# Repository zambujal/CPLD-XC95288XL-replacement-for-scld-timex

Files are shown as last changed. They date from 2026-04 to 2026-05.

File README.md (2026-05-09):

# Timex SCLD CPLD Replacement (TC2068)
Target device: Xilinx XC95288XL CPLD

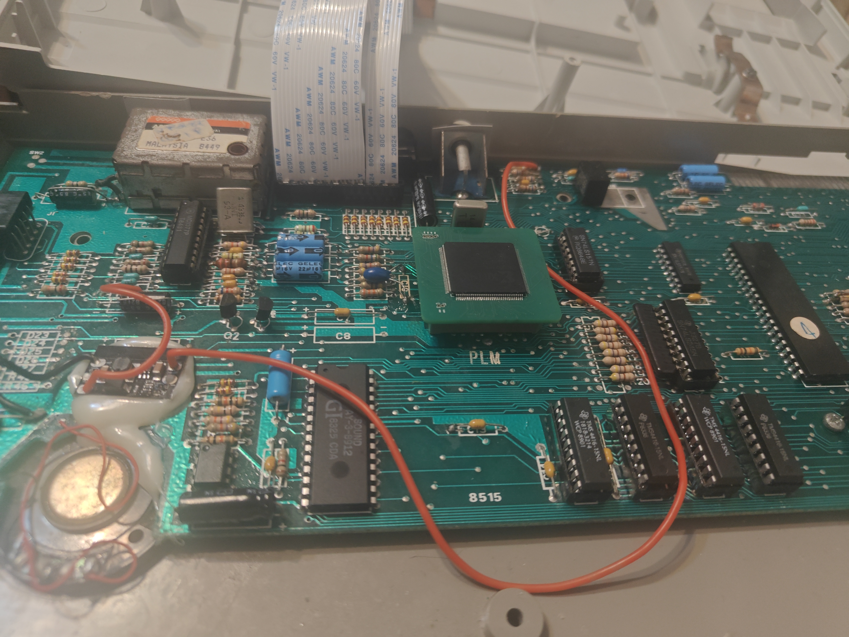
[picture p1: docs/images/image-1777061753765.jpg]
Working Setup


A fully working CPLD replacement for the Timex SCLD — validated on real hardware.

✔ Timing fixes
✔ CMOS Z84 compatible
✔ NMOS Z80 compatible
✔ Tested on real hardware

> This is not just a simulation model — this version works on real hardware.
---
### ERRATA: 
# ERRATA - scld_devboard.vhd

## Output Pin High Impedance - Code Bug

### Problem

The `OE` signal is hardwired to `'1'`, which means the condition:

```vhdl
SIGNAL <= SIGNAL_o_s WHEN OE='1' else 'Z';
```

**never** produces high impedance on any output pin. This is a **code bug**, not a Xilinx hardware limitation.

The XC95288XL correctly implements tristate output buffers (OBUFT) when the condition actually varies — as demonstrated by the `CPUCLK` fix, where using `CPUCLK_o_s='0'` as the condition produces true tristate behaviour.

### Consequence

All output pins remain **push-pull at 3.3V**. Pull-up resistors placed on these output pins have no effect on the HIGH level, since the CPLD actively drives 3.3V. The output will never float to allow an external pull-up to reach 5V.

Pull-ups are only effective where true tristate occurs or on input/bidirectional pins.

### Signal Status

| Signal | Status | Notes |
|---|---|---|
| `CPUCLK` | ✅ Fixed | Condition changed to `CPUCLK_o_s='0'` — true tristate. Use 1kΩ pull-up to 5V (max IOL = 8mA per datasheet). Required for CMOS Z80 compatibility. |
| `TPOUT` | ✅ Fixed | External audio buffer added. |
| `INT` | ✅ Fixed | Open-drain via `'0'/'1'` — correct behaviour, no pull-up to `'Z'` needed. |
| `D`, `MA` | ✅ OK | Bidirectional `inout` — tristate works correctly. |
| `KB` | ✅ OK | Input only — 10kΩ pull-ups correct and required. |
| All other outputs | ⚠️ Push-pull 3.3V | Functional for 5V TTL/CMOS receivers (VIH min = 2.0V). No external buffer needed unless 5V level is required. |

### What Works Despite the Bug

The 3.3V push-pull output is sufficient for most 5V TTL and CMOS receivers (VIH min = 2.0V). The system works correctly with an NMOS Z80. For CMOS Z80, the CPUCLK requires a higher voltage level — fixed with the true tristate + pull-up solution above.

### TODO

- `CPUCLKB` — may benefit from external buffer if CMOS Z80 is used.
- Review and fix the `OE` condition across all output assignments, replacing with signal-specific conditions where true tristate is required.

### Kicad final Beta PCB

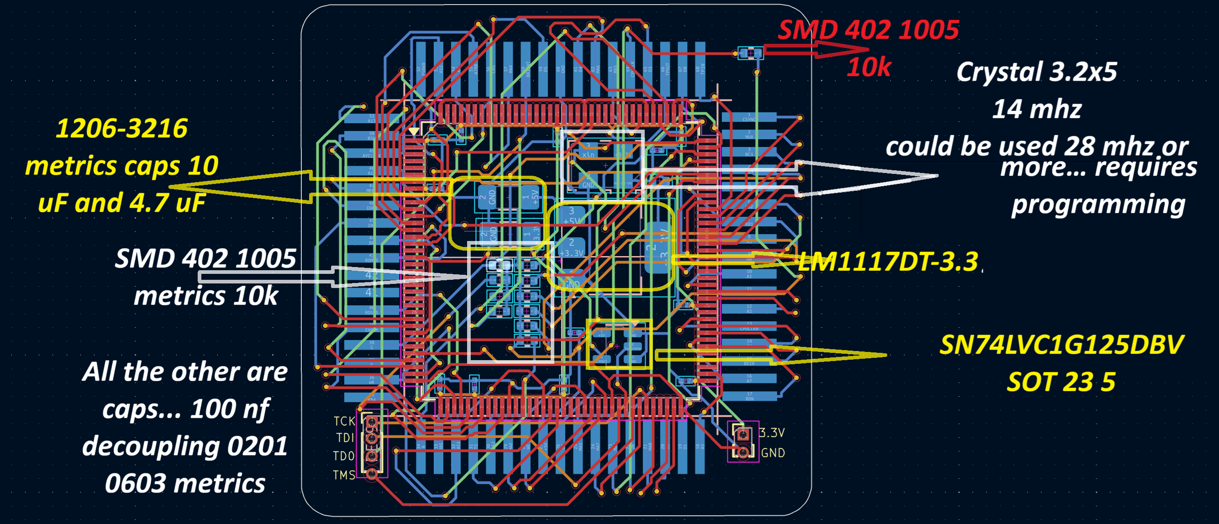
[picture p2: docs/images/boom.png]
kicad work


My last iteration of the PCB (work in progress...maybe). You might use 10uF on both rails 5v and 3.2v ... I really don't know why I changed from two caps at same value 10 uF, 10 uF is great for the two big caps... don't used electrolitic though "space"... I had to use smaller stuff, but in the end I guess ...I could had used bigger stuff to be easier to solder.

---

## 🎥 Demo (Real Hardware)

> ✔ Proof of real hardware operation — not just simulation

### CPLD Replacement Running (Timex 2048 "Timmy")

https://www.youtube.com/watch?v=t5ia4-bkabo

---

### CPLD Replacement Running (Timex 2068)

https://www.youtube.com/watch?v=evhCbX4_XCQ

---

## 📸 Hardware & Debug

> Real hardware validation using logic analysis and live system testing.

### Logic Analyzer (Timing Validation)

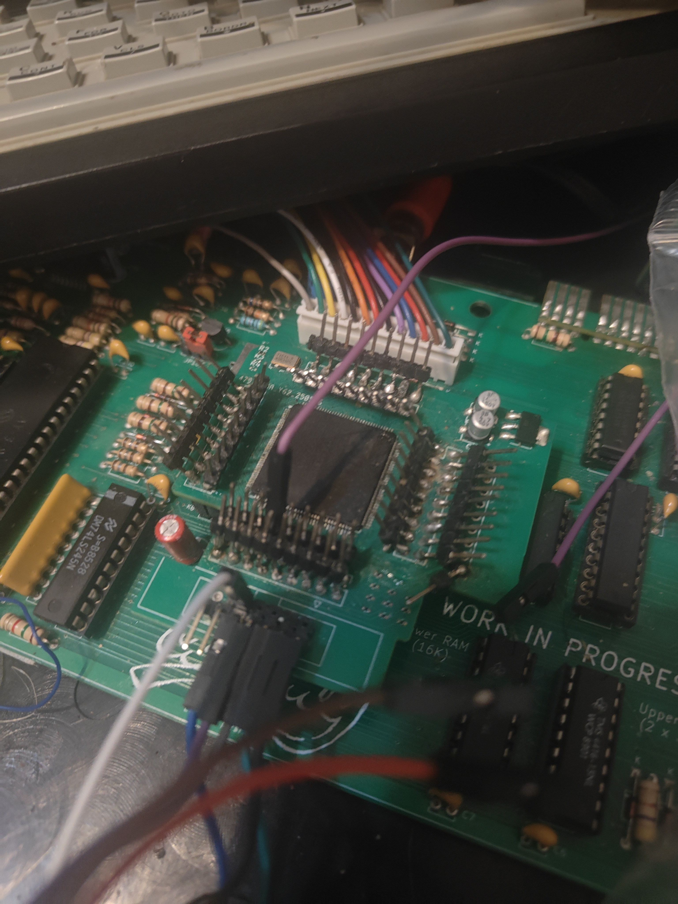
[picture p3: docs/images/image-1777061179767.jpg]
Logic Analyzer


Captured signals used to debug and align timing (MREQ, RAS, CAS, multiplexing).

---

### Timex 2048 ("Timmy") Running with Guzman Logic Analyzer

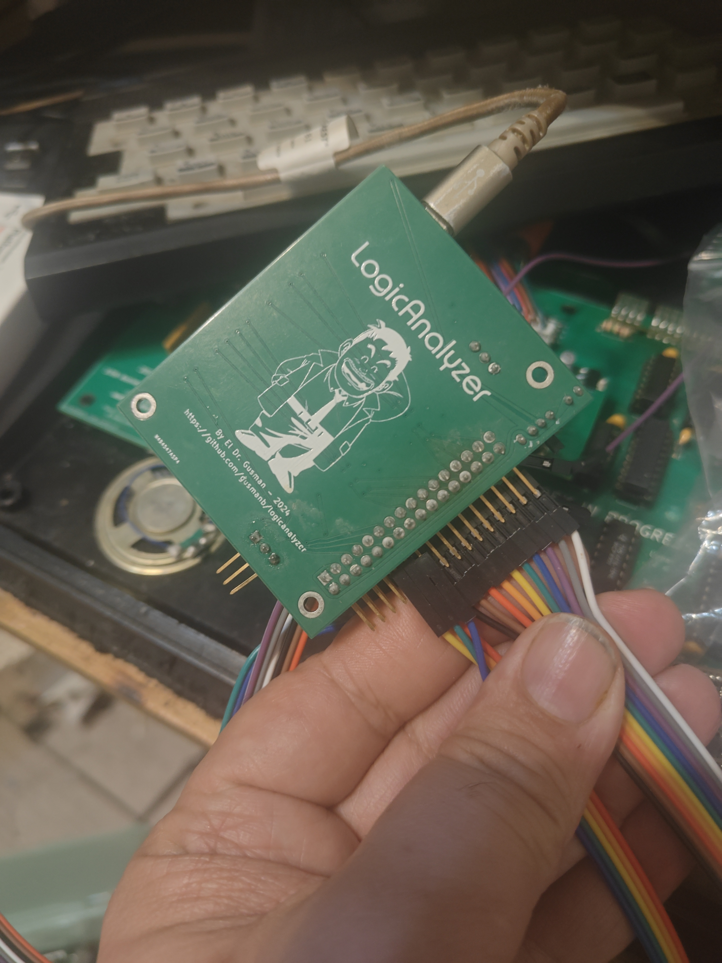
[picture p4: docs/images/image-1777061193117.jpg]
Timmy Running


System running with CPLD-based SCLD replacement, monitored using a Guzman logic analyzer.

---

### Timex 2048 Test System ("Timmy")

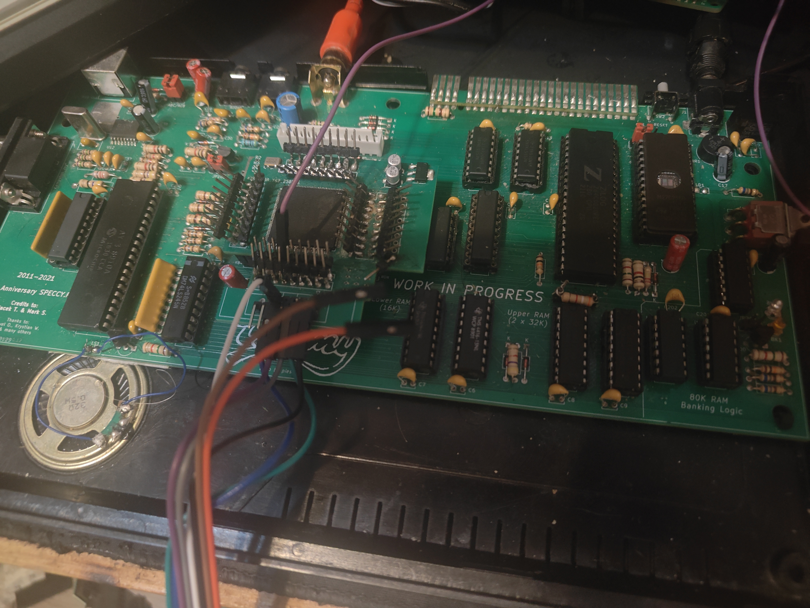
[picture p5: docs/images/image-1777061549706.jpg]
Timmy Board


Initial test platform where the CPLD implementation was first validated.

---

## 🔌 Hardware Integration Details

The CPLD board was designed to interface with the original Timex hardware using a practical and non-invasive approach.

> ⚠️ No permanent modification to the original system is required (after socket installation).

---

### CPLD Prototype (Hand-Assembled)

CPLD Prototype

Hand-assembled CPLD final prototype (beta version) .

CPLD Prototype

---

### Development Setup (Debug & Measurement)

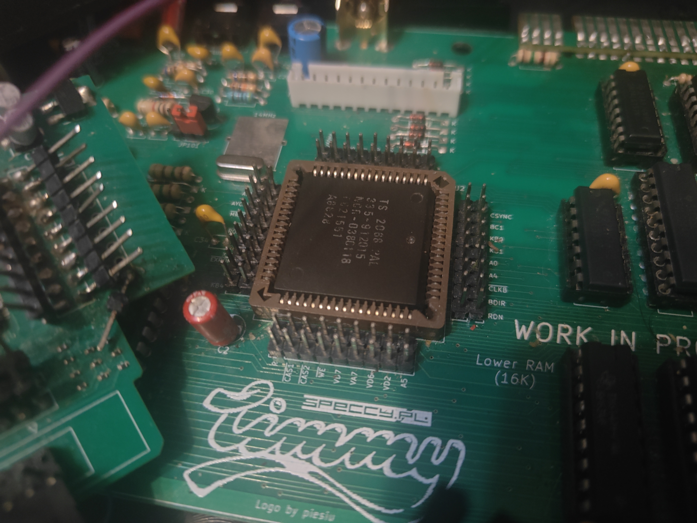
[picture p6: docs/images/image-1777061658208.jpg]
Prototype Debug


Temporary wiring and probe points were used during development to access internal signals for measurement and debugging.

These connections were used to:

* Probe critical signals (MREQ, RAS, CAS, etc.)
* Validate timing behaviour
* Debug hardware interactions

⚠️ Note:
Signal artifacts such as spikes/noise observed during this stage were related to the measurement setup, not the final design.

---

### Final Hardware Integration

Final Integration

Final CPLD implementation using right-angle (90°) pin headers.

---

### 90° Pin Integration Technique (Final Design)

Right-angle (90°) pin headers are used as part of the final design to interface the CPLD board with the installed PLCC socket.

This provides:

* Correct alignment with the socket
* Reliable electrical connections
* Mechanical stability
* Easy installation and removal

---

### PLCC Socket Adaptation

The original SCLD is soldered directly to the motherboard in Timex machines.

For this project, a PLCC socket was installed to allow easy testing and replacement without repeatedly soldering components.

This enables:

* Safe insertion and removal of the CPLD board
* Faster development iterations
* Reduced risk of damage to the motherboard

---

## ⚡ Quick Start

1. Program the CPLD with `scld_devboard.jed`
2. Insert into the installed PLCC socket
3. Power on

Done.

---

## 🧠 Overview

This project implements the Timex TC2068 SCLD using a CPLD.

Used in:

* Timex Computer 2048
* Timex Computer 2068

The SCLD is responsible for:

* Memory paging
* Video timing
* Bus arbitration
* DRAM access

---

## 🔧 What was fixed / improved

The original implementation worked on the Timex 2048 with some limitations and was implemented on a smaller CPLD.

However, it was incomplete and did not correctly support key features required for full Timex 2068 compatibility.

This implementation focuses on correct behaviour on real hardware and full system compatibility.

Key improvements include:

- Proper support for Timex 2068 memory paging  
- Implementation of missing I/O behaviour (`IN FF`, `IN F4`)  
- Correct handling of bank switching and EXROM behaviour  
- Timing fixes for reliable operation with both NMOS and CMOS Z80 CPUs  
- Improved stability and DRAM access behaviour  
- Full validation on real hardware (not just simulation)  
---

## 🧪 Development Process

* Started from original VHDL implementation
* Observed incorrect behaviour on real hardware
* Analysed signals using a logic analyzer
* Adjusted timing and internal logic
* Tested with multiple Z80 variants (NMOS / CMOS)
* Validated behaviour against real systems

---

## 🧪 Development Approach

The project evolved through direct hardware testing rather than strict schematic-first design.

Key fixes were implemented and validated directly on the PCB.

---

## 🧰 Hardware

### Final PCB

`Hardware/PCB/Beta/`

Final PCB design used for the working CPLD-based SCLD replacement.

---

### Prototype PCB

`Hardware/PCB/prototype`

Early prototype used during development and testing.

---

### Prototype Schematic

`Hardware/Schematics`

⚠️ Note:
This schematic corresponds to the prototype stage and may differ from the final PCB.

---

## 💾 Firmware

### Prebuilt

`firmware/jed`

* `scld_devboard.jed` → ready to program

---

### Source Code

`firmware/src/`

* VHDL implementation of the SCLD

---

### Constraints

`firmware/constraints/`

* UCF file defining CPLD pin mapping

---

### Xilinx Project

`firmware/xilinx/full_project/`

Full Xilinx ISE project used during development.

⚠️ Note:
Includes generated files (`remote/`, logs, etc.) to preserve the working environment.

Rebuilding is optional — the `.jed` file is sufficient.

---

## 🔍 Validation

Validated against real hardware:

* Video output behaviour
* Memory timing
* System stability
* CPU interaction timing

---

## 🙏 Credits

Based on work from:

- Load ZX Spectrum Museum  
- Álvaro Lopes  
- Paulo Cortesão  

Support:
- João Diogo 
- Hugo Pinto
- Marco Pais
- Inácio Santos
- Fernando

---

### 🧪 Technical Support & Testing

Special thanks to Rui Ribeiro:

- Provided  ROMs used for validation  
- Helped verify behaviour against real systems  
- Shared knowledge of Timex hardware and timing and the weird timex 2068 paging...

---

### 🧠 Implementation (VHDL, Hardware & PCB Design)

- António Vítor  

Complete implementation and validation:

- VHDL development and debugging  
- Timing fixes (MREQ, RAS/CAS, multiplexing)  
- Hardware design and integration  
- PCB design using KiCad  
- CPLD implementation and testing  
- Real hardware validation  

This includes both the logic implementation and the full hardware solution.

---

## 📜 License

Creative Commons Attribution-ShareAlike 4.0 International License

https://creativecommons.org/licenses/by-sa/4.0/

---

## ⚖️ Trademarks

TIMEX is a trademark of TIMEX GROUP USA, INC

The authors are not affiliated with or endorsed by the trademark holders.

Xilinx is a registered trademark of Xilinx, Inc.

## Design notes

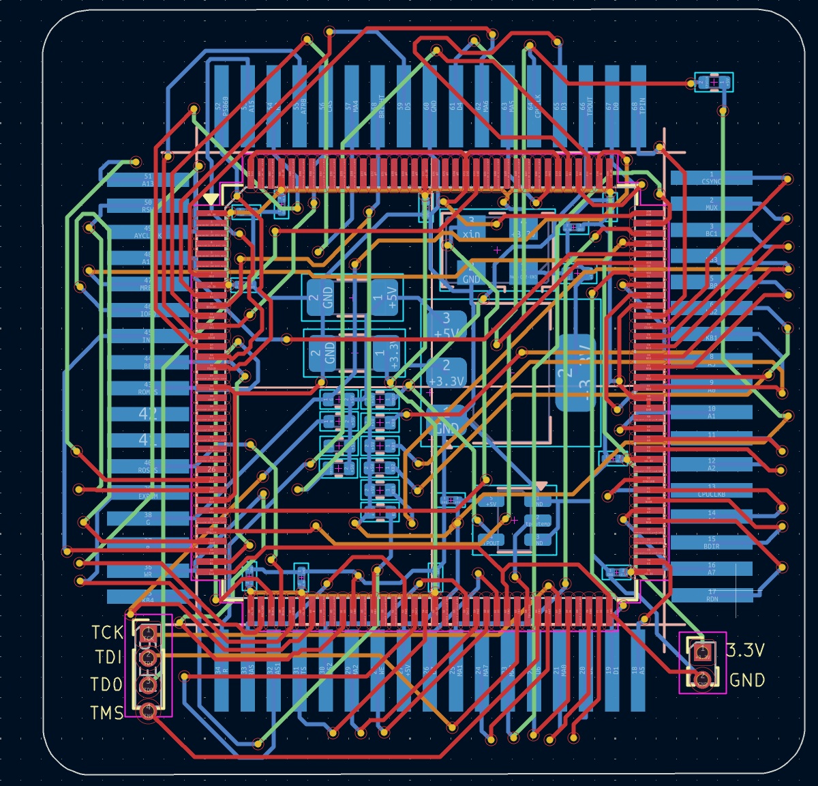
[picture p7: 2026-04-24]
docs/images/kicad1.jpg

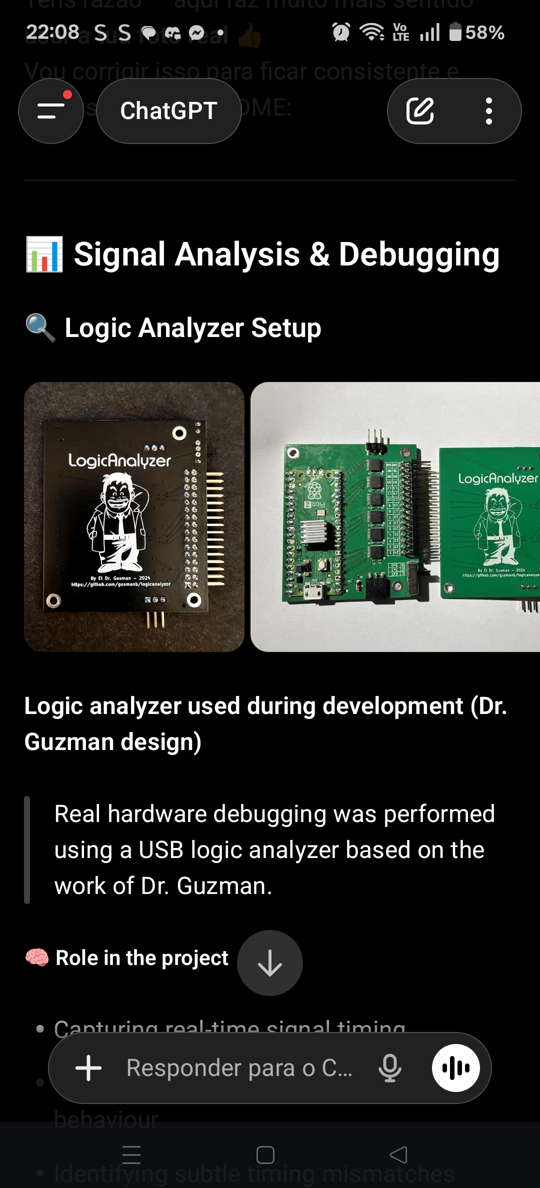
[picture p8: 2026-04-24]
docs/images/Screenshot_2026-04-24-22-08-57-02_96b26121e545231a3c569311a54cda96.jpg

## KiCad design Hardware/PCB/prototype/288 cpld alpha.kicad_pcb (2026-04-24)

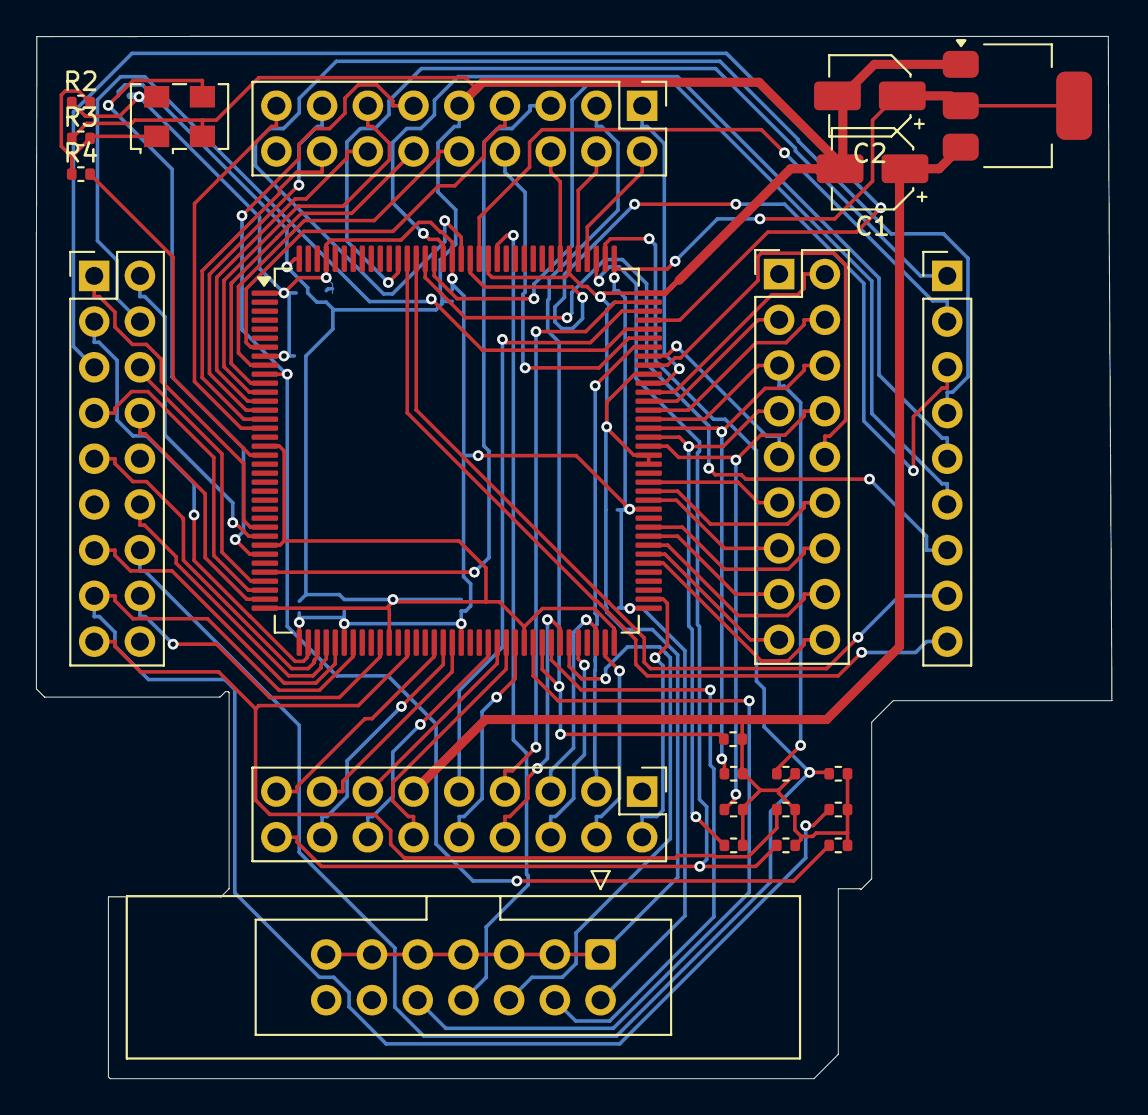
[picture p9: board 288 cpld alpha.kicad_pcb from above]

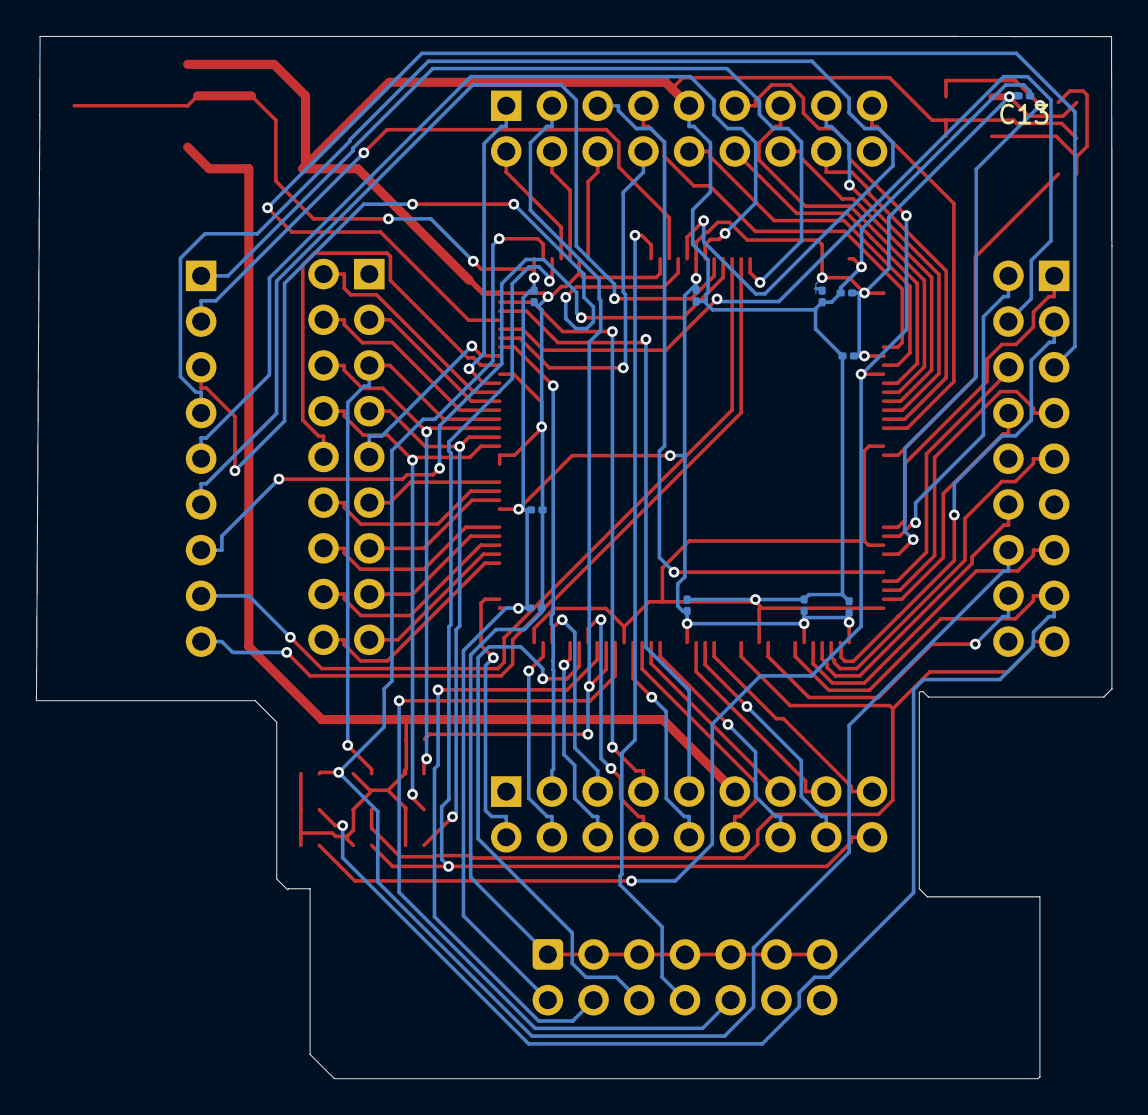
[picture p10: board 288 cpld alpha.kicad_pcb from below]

Board: 2 copper layers, 59.8 x 57.9 mm, 35 parts (11 on the bottom side), 83 nets.

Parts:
C1, C2: C_Small; CP_Elec_4x5.3
C3, C4, C5, C6, C7, C8, C9, C10, C11, C12, C13: C_Small; C_0201_0603Metric
J1, J3, J4, J5: Conn_02x09_Counter_Clockwise; PinHeader_2x09_P2.54mm_Vertical
J2: Conn_01x09_Pin; PinHeader_1x09_P2.54mm_Vertical
J6: JTAG-10; IDC-Header_2x07_P2.54mm_Latch_Vertical
R1, R2, R3, R4, R25, R26, R27, R28, R29, R30, R31, R32, R33: R; R_0402_1005Metric
U1: LM1117DT-3.3; SOT-223-3_TabPin2
U2: XCR3256-TQ144; TQFP-144_20x20mm_P0.5mm
X2: ASE-14MHz; Oscillator_SMD_EuroQuartz_XO53-4Pin_5.0x3.2mm

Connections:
+3.3V: C2.1, C3.2, C4.2, C5.2, C6.2, C7.2, C8.2, C9.2, C10.2, C11.2, C12.2, C13.2, J6.2 (vcc), R2.1, U1.2 (VO), U2.1 (VCCIO), U2.8 (VCCINT), U2.37 (VCCIO), U2.42 (VCCINT), U2.55 (VCCIO), U2.73 (VCCIO), U2.84 (VCCINT), U2.109 (VCCIO), U2.127 (VCCIO), U2.141 (VCCINT), X2.4 (Vdd)
+5V: C1.1, J4.11, R1.2, R25.2, R26.2, R27.2, R28.2, R29.2, R30.2, R31.2, R32.2, R33.2, U1.3 (VI)
/A0: J5.10, U2.100 (I/O_geral)
/A1: J5.11, U2.87 (I/O_geral)
/A2: J5.13, U2.85 (I/O_geral)
/A3: J5.9, U2.101 (I/O_geral)
/A4: J5.12, U2.86 (I/O_geral)
/A5: J4.2, U2.74 (I/O_geral)
/A6: J5.15, U2.81 (I/O_geral)
/A7: J5.17, U2.79 (I/O_geral)
/A7RB: J3.14, U2.13 (I/O_geral)
/A13: J1.1, U2.27 (I/O_geral)
/A14: J1.4, U2.104 (I/O_geral)
/A15: J3.16, U2.15 (I/O_geral)
/AYCLOCK: J1.3, U2.38 (Global_Clock_3)
/B: J1.15, R32.1, U2.43 (I/O_geral)
/BC1: J5.4, U2.95 (I/O_geral)
/BDIR: J5.16, U2.80 (I/O_geral)
/BE: J1.8, U2.35 (I/O_geral)
/BRIGHT: J3.11, R33.1, U2.10 (I/O_geral)
/CAS: J3.13, U2.12 (I/O_geral)
/CAS1: J4.16, U2.53 (I/O_geral)
/CAS2: J4.14, U2.58 (I/O_geral)
/CPUCLK: J3.5, U2.32 (Global_Clock_2)
/CPUCLKB: J5.14, U2.82 (I/O_geral)
/CSYNC: J5.2, U2.97 (I/O_geral)
/D0: J3.2, U2.112 (I/O_geral)
/D1: J4.3, U2.102 (I/O_geral)
/D2: J4.4, U2.71 (I/O_geral)
/D3: J3.4, U2.113 (I/O_geral)
/D4: J3.8, U2.103 (I/O_geral)
/D5: J3.10, U2.9 (I/O_geral)
/D6: J4.6, U2.68 (I/O_geral)
/D7: J4.10, U2.61 (I/O_geral)
/EXROM: J1.13, U2.41 (I/O_geral)
/G: J1.14, R31.1, U2.110 (I/O_geral)
/INT: J1.7, U2.34 (I/O_geral)
/IORQ: J1.6, U2.33 (I/O_geral)
/KB0: J5.6, R25.1, U2.93 (I/O_geral)
/KB1: J5.8, R26.1, U2.91 (I/O_geral)
/KB2: J5.7, R27.1, U2.92 (I/O_geral)
/KB3: J5.5, R28.1, U2.94 (I/O_geral)
/KB4: J1.17, R29.1, U2.49 (I/O_geral)
/MA0: J4.5, U2.70 (I/O_geral)
/MA1: J4.9, U2.106 (I/O_geral)
/MA2: J4.13, U2.59 (I/O_geral)
/MA3: J4.7, U2.107 (I/O_geral)
/MA4: J3.12, U2.11 (I/O_geral)
/MA5: J3.6, U2.115 (I/O_geral)
/MA6: J3.7, U2.7 (I/O_geral)
/MA7: J4.8, U2.66 (I/O_geral)
/MREQ: J1.5, U2.105 (I/O_geral)
/MUX: J5.3, U2.96 (I/O_geral)
/P5060: J3.17, U2.16 (I/O_geral)
/R: J4.18, R30.1, U2.111 (I/O_geral)
/RAS: J4.17, U2.52 (I/O_geral)
/RD: J3.15, U2.14 (I/O_geral)
/RDN: J5.18, U2.78 (I/O_geral)
/ROMCS: J1.9, U2.39 (I/O_geral)
/ROSCS: J1.12, U2.40 (I/O_geral)
/RSH: J1.2, U2.28 (I/O_geral)
/TCK: J6.6 (TCK), U2.67 (E0/TCK)
/TDI: J6.10 (TDI), U2.63 (J0/TDI)
/TDO: J6.8 (TDO), U2.122 (A2/TDO)
/TMS: J6.4 (TMS), U2.65 (N0/TMS)
/TPIN: J3.1, U2.98 (I/O_geral)
/TPOUT: J3.3, R1.1, U2.64 (I/O_geral)
/TS: J4.15, U2.54 (I/O_geral)
/WE: J4.12, U2.60 (I/O_geral)
/WR: J1.16, U2.46 (I/O_geral)
/p1: J2.3, U2.125 (I/O_geral)
/p2: J2.4, U2.126 (I/O_geral)
/p3: J2.5, U2.128 (I/O_geral)
/p4: J2.6, U2.129 (I/O_geral)
/p5: J2.7, U2.130 (I/O_geral)
/p6: J2.8, U2.131 (I/O_geral)
/p7: J2.9, U2.132 (I/O_geral)
/p8: J2.2, U2.124 (I/O_geral)
/p9: J2.1, U2.133 (I/O_geral)
/xin: U2.30 (Global_Clock_1), X2.3 (OUT)
/xout: R4.2, U2.19 (I/O_geral)
GND: C1.2, C2.2, C3.1, C4.1, C5.1, C6.1, C7.1, C8.1, C9.1, C10.1, C11.1, C12.1, C13.1, J3.9, J6.1 (gnd), J6.3 (gnd), J6.5 (gnd), J6.7 (gnd), J6.9 (gnd), J6.11 (gnd), J6.13 (gnd), R3.1, U1.1 (GND), U2.18 (GND), U2.29 (GND), U2.36 (GND), U2.47 (GND), U2.62 (GND), U2.72 (GND), U2.89 (GND), U2.90 (GND), U2.99 (GND), U2.108 (GND), U2.114 (GND), U2.123 (GND), U2.144 (GND), X2.2 (GND)
unnamed: R2.2, R3.2, R4.1, X2.1 (EN)

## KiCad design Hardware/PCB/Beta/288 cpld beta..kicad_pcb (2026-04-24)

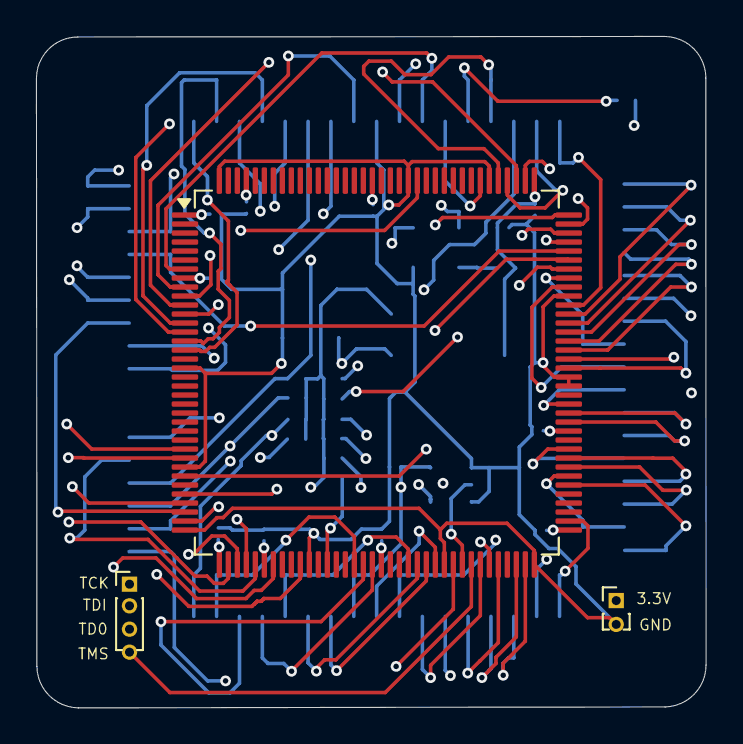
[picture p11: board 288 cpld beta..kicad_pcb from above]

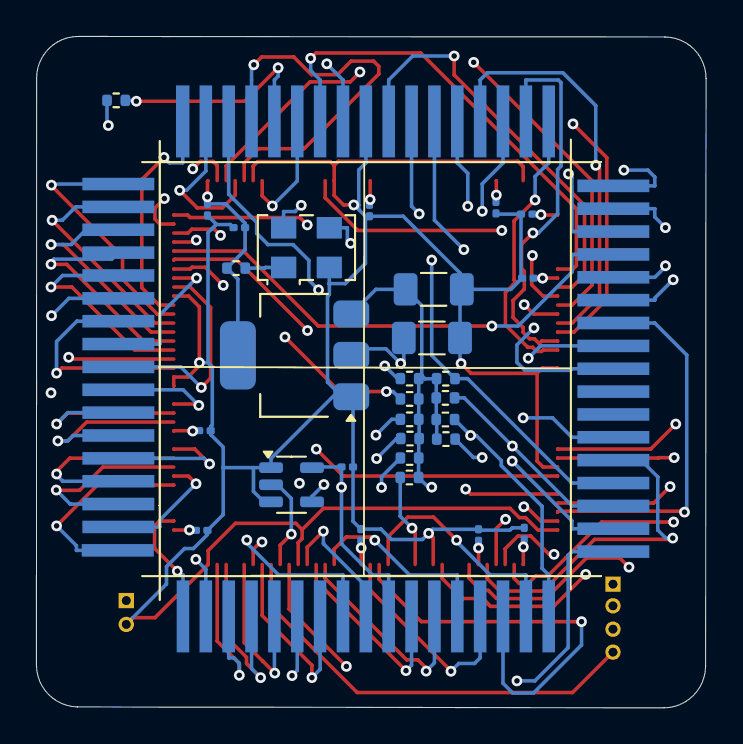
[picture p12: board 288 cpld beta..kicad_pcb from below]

Board: 4 copper layers, 37.2 x 37.3 mm, 33 parts (29 on the bottom side), 74 nets.

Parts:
C1, C2: C_Small; C_1206_3216Metric_Pad1.33x1.80mm_HandSolder
C3, C4, C5, C6, C7, C8, C9, C9x, C10, C11, C12, C13: C_Small; C_0201_0603Metric
R1, R2, R25, R26, R27, R28, R29, R30, R31, R32, R33: R; R_0402_1005Metric
R2pullclock: 330; R_0402_1005Metric
REF9: PinHeader_1x04_P1.00mm_Vertical
REF10: PinHeader_1x02_P1.00mm_Vertical
U1: LM1117DT-3.3; SOT-223-3_TabPin2
U2: XCR3256-TQ144; TQFP-144_20x20mm_P0.5mm
U3: SN74LVC1G125DBV; SOT-23-5
X2: ASE-14MHz; Oscillator_SMD_EuroQuartz_XO53-4Pin_5.0x3.2mm
programação: 68 scld; 68_scld (2)

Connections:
+3.3V: C2.1, C3.2, C4.2, C5.2, C6.2, C7.2, C8.2, C9.2, C10.2, C11.2, C12.2, C13.2, R2.1, REF10.1, U1.2 (VO), U2.1 (VCCIO), U2.8 (VCCINT), U2.37 (VCCIO), U2.42 (VCCINT), U2.55 (VCCIO), U2.73 (VCCIO), U2.84 (VCCINT), U2.109 (VCCIO), U2.127 (VCCIO), U2.141 (VCCINT), X2.4 (Vdd)
+5V: C1.1, C9x.2, R1.2, R2pullclock.1, R25.2, R26.2, R27.2, R28.2, R29.2, R30.2, R31.2, R32.2, R33.2, U1.3 (VI), U3.5 (VCC), programação.27
/A0: U2.100 (I/O_geral), programação.9
/A1: U2.87 (I/O_geral), programação.10
/A2: U2.85 (I/O_geral), programação.12
/A3: U2.101 (I/O_geral), programação.8
/A4: U2.86 (I/O_geral), programação.11
/A5: U2.74 (I/O_geral), programação.18
/A6: U2.81 (I/O_geral), programação.14
/A7: U2.79 (I/O_geral), programação.16
/A7RB: U2.13 (I/O_geral), programação.55
/A13: U2.27 (I/O_geral), programação.51
/A14: U2.104 (I/O_geral), programação.48
/A15: U2.15 (I/O_geral), programação.53
/AYCLOCK: U2.38 (Global_Clock_3), programação.49
/B: R32.1, U2.43 (I/O_geral), programação.37
/BC1: U2.95 (I/O_geral), programação.3
/BDIR: U2.80 (I/O_geral), programação.15
/BE: U2.35 (I/O_geral), programação.44
/BRIGHT: R33.1, U2.10 (I/O_geral), programação.58
/CAS: U2.12 (I/O_geral), programação.56
/CAS1: U2.53 (I/O_geral), programação.32
/CAS2: U2.58 (I/O_geral), programação.30
/CPUCLK: R2pullclock.2, U2.32 (Global_Clock_2), programação.64
/CPUCLKB: U2.82 (I/O_geral), programação.13
/CSYNC: U2.97 (I/O_geral), programação.1
/D0: U2.112 (I/O_geral), programação.67
/D1: U2.102 (I/O_geral), programação.19
/D2: U2.71 (I/O_geral), programação.20
/D3: U2.113 (I/O_geral), programação.65
/D4: U2.103 (I/O_geral), programação.61
/D5: U2.9 (I/O_geral), programação.59
/D6: U2.68 (I/O_geral), programação.22
/D7: U2.61 (I/O_geral), programação.26
/EXROM: U2.41 (I/O_geral), programação.39
/G: R31.1, U2.110 (I/O_geral), programação.38
/INT: U2.34 (I/O_geral), programação.45
/IORQ: U2.33 (I/O_geral), programação.46
/KB0: R25.1, U2.93 (I/O_geral), programação.5
/KB1: R26.1, U2.91 (I/O_geral), programação.7
/KB2: R27.1, U2.92 (I/O_geral), programação.6
/KB3: R28.1, U2.94 (I/O_geral), programação.4
/KB4: R29.1, U2.49 (I/O_geral), programação.35
/MA0: U2.70 (I/O_geral), programação.21
/MA1: U2.106 (I/O_geral), programação.25
/MA2: U2.59 (I/O_geral), programação.29
/MA3: U2.107 (I/O_geral), programação.23
/MA4: U2.11 (I/O_geral), programação.57
/MA5: U2.115 (I/O_geral), programação.63
/MA6: U2.7 (I/O_geral), programação.62
/MA7: U2.66 (I/O_geral), programação.24
/MREQ: U2.105 (I/O_geral), programação.47
/MUX: U2.96 (I/O_geral), programação.2
/P5060: U2.16 (I/O_geral), programação.52
/R: R30.1, U2.111 (I/O_geral), programação.34
/RAS: U2.52 (I/O_geral), programação.33
/RD: U2.14 (I/O_geral), programação.54
/RDN: U2.78 (I/O_geral), programação.17
/ROMCS: U2.39 (I/O_geral), programação.43
/ROSCS: U2.40 (I/O_geral), programação.40
/RSH: U2.28 (I/O_geral), programação.50
/TCK: REF9.1, U2.67 (E0/TCK)
/TDI: REF9.2, U2.63 (J0/TDI)
/TDO: REF9.3, U2.122 (A2/TDO)
/TMS: REF9.4, U2.65 (N0/TMS)
/TPIN: U2.98 (I/O_geral), programação.68
/TPOUT: R1.1, U3.4, programação.66
/TS: U2.54 (I/O_geral), programação.31
/WE: U2.60 (I/O_geral), programação.28
/WR: U2.46 (I/O_geral), programação.36
/xin: U2.30 (Global_Clock_1), X2.3 (OUT)
GND: C1.2, C2.2, C3.1, C4.1, C5.1, C6.1, C7.1, C8.1, C9.1, C9x.1, C10.1, C11.1, C12.1, C13.1, REF10.2, U1.1 (GND), U2.18 (GND), U2.29 (GND), U2.36 (GND), U2.47 (GND), U2.62 (GND), U2.72 (GND), U2.89 (GND), U2.90 (GND), U2.99 (GND), U2.108 (GND), U2.114 (GND), U2.123 (GND), U2.144 (GND), U3.1, U3.3 (GND), X2.2 (GND), programação.60
unnamed: R2.2, X2.1 (EN)
tpoutemp: U2.64 (I/O_geral), U3.2

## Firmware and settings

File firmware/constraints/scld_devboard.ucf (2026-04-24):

NET	"TPIN" 		LOC="98";
NET	"D<0>" 		LOC="112";
NET	"D<3>" 		LOC="113";
//NET	"CPUCLK"	LOC="4";
NET	"MA<5>"		LOC="115";
NET	"MA<6>"		LOC="7";
NET	"D<4>"		LOC="103";
NET	"D<5>"		LOC="9";
NET	"BRIGHT"	LOC="10";
NET	"MA<4>"		LOC = "11";
NET	"CAS" 		LOC = "12";
NET	"A7RB" 		LOC = "13";
NET	"RD" 		LOC = "14";
NET	"A<15>" 	LOC = "15";
NET	"P5060"		LOC = "16";
//NET	"NOE" 		LOC="18";
NET	"SCLD_CLK"	LOC = "30";
NET	"CPUCLK"	LOC = "32";
NET	"A<13>"		LOC = "27";
NET	"RFSH"		LOC = "28";
NET	"AYCLK"		LOC = "38";
NET	"A<14>"		LOC = "104";
NET	"MREQ"		LOC = "105";
NET	"IORQ"		LOC = "33";
NET	"INT"		LOC = "34";

NET	"BE"		LOC = "35";
NET	"ROMCS"		LOC = "39";
NET	"ROSCS"		LOC = "40";
NET	"EXROM"		LOC = "41";
NET	"G"		LOC = "110";
NET	"B"		LOC = "43";
NET	"WR"		LOC = "46";
NET	"KB<4>"		LOC = "49";

NET	"RAS"		LOC = "52";
NET	"CAS1"		LOC = "53";
NET	"TS"		LOC = "54";
NET	"CAS2"		LOC = "58";
NET	"MA<2>"		LOC = "59";
NET	"MWE"		LOC = "60";
NET	"D<7>"		LOC = "61";

NET	"R"		LOC = "111";
NET	"TPOUT"		LOC = "64";
NET	"MA<1>"		LOC = "106";
NET	"MA<7>"		LOC = "66";
NET	"MA<3>"		LOC = "107";
NET	"D<6>"		LOC = "68";
NET	"MA<0>"		LOC = "70";
NET	"D<2>"		LOC = "71";
NET	"D<1>"		LOC = "102";

NET	"A<5>"		LOC = "74";
NET	"RDN"		LOC = "78";
NET	"A<7>"		LOC = "79";
NET	"BDIR"		LOC = "80";
NET	"A<6>"		LOC = "81";
NET	"CPUCLKB"	LOC = "82";
NET	"A<2>"		LOC = "85";
NET	"A<4>"		LOC = "86";

NET	"A<1>"		LOC = "87";
NET	"A<0>"		LOC = "100";
NET	"A<3>"		LOC = "101";
NET	"KB<1>"		LOC = "91";
NET	"KB<2>"		LOC = "92";
NET	"KB<0>"		LOC = "93";
NET	"KB<3>"		LOC = "94";
NET	"BC1"		LOC = "95";
NET	"MUX"		LOC = "96";
NET	"CSYNC"		LOC = "97";

NET 	"SCLD_CLK" 	TNM_NET = SCLD_CLK;
NET   "EPROM_CE" LOC = "132";
TIMESPEC TS_SCLD_CLK = PERIOD "SCLD_CLK" 14 MHz HIGH 50%;

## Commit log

2025-08-03 Add files via upload
    flash para programar o xilinx...
    cpld para o timmy...
2026-04-24 Create pcb
2026-04-24 Add files via upload
    beta mas most likely final
    [288 cpld beta..kicad_pcb]
2026-04-24 Enhance README with hardware integration and debug details
    Expanded hardware integration details and added sections on CPLD prototype, development setup, final PCB solution, PLCC socket compatibility, and debugging techniques.
2026-04-24 Revise README for hardware integration and CPLD details
    Updated hardware integration details and clarified CPLD prototype information.
2026-04-24 Revise CPLD prototype description and add image
    Updated description of the CPLD prototype and added a new image.
2026-04-24 Add target device information to README
2026-04-24 Specify target device in README
    Added target device information for clarity.
2026-04-25 Add Kicad final Beta PCB section to README
    Added section for Kicad final Beta PCB with image.
2026-04-26 Update image in README for Kicad PCB
2026-04-26 Update PCB notes in README
    Clarified PCB notes regarding capacitor usage.
2026-04-26 Update PCB description for clarity
    Clarified reasoning for capacitor selection in PCB description.
2026-04-26 Update PCB description in README.md
    Expanded explanation about PCB capacitor choices and soldering.
2026-05-09 Documented errata and output pin issues in README
    Added errata section detailing a code bug with the OE signal and its consequences on output pin behavior. Included signal status and what works despite the bug.
